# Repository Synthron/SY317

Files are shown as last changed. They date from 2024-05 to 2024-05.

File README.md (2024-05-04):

# Switching Power Supply Modules

## SY317
78xx compatible Switching Regulator

 - Input Voltage: 4.5V .. 24V
 - Output Voltage: 1.1V .. 16V
 - Output Current: 3A
 - Switching Frequency: 500kHz
 - Efficiency: 85-95% 
 - Output Ripple: <50mV

pincompatible to the popular 78xx series linear voltage regulators

Very small form factor at 10x25mm dimensions

## CB350
High current Switching Regulator

- 12..24V Input
- 5V2, 6V2, 7V4 and 8V4 fixed output
  - use solder bridge to select output voltage
  - different resistor values for voltages given in schematic
- 12A of current!

Intended for Servo Control, featuring 4 Pin-Headers for Servo control

features pin header for additional SY317 module for an additional variable 3A output voltage

compact form factor at 25x50mm dimensions

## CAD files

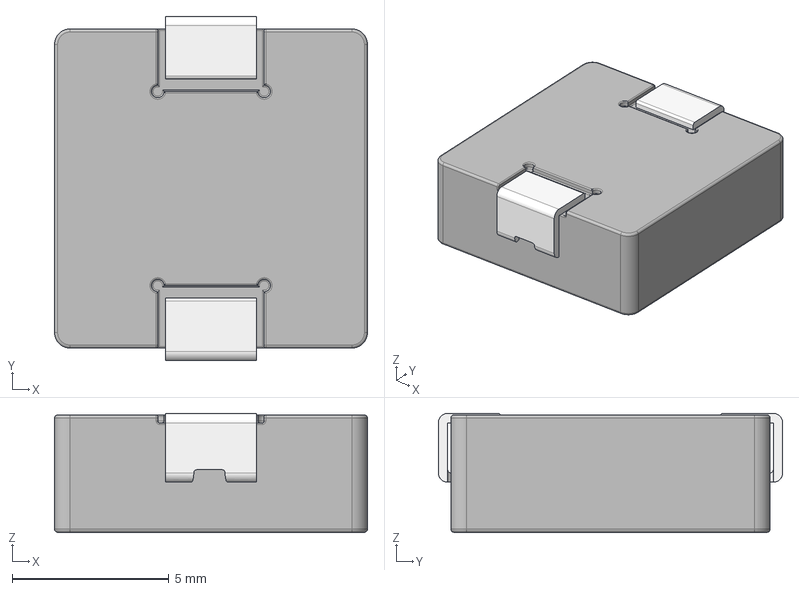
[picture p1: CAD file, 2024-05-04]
CB350/SRP1038C-150M.stp
10.0 x 11.0 x 3.81 mm

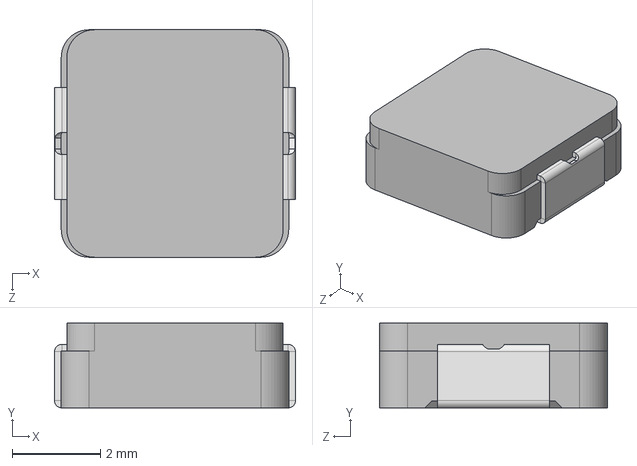
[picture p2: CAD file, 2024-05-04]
SY317/IHLP2020BZERR10M11.stp
5.45 x 1.92 x 5.15 mm

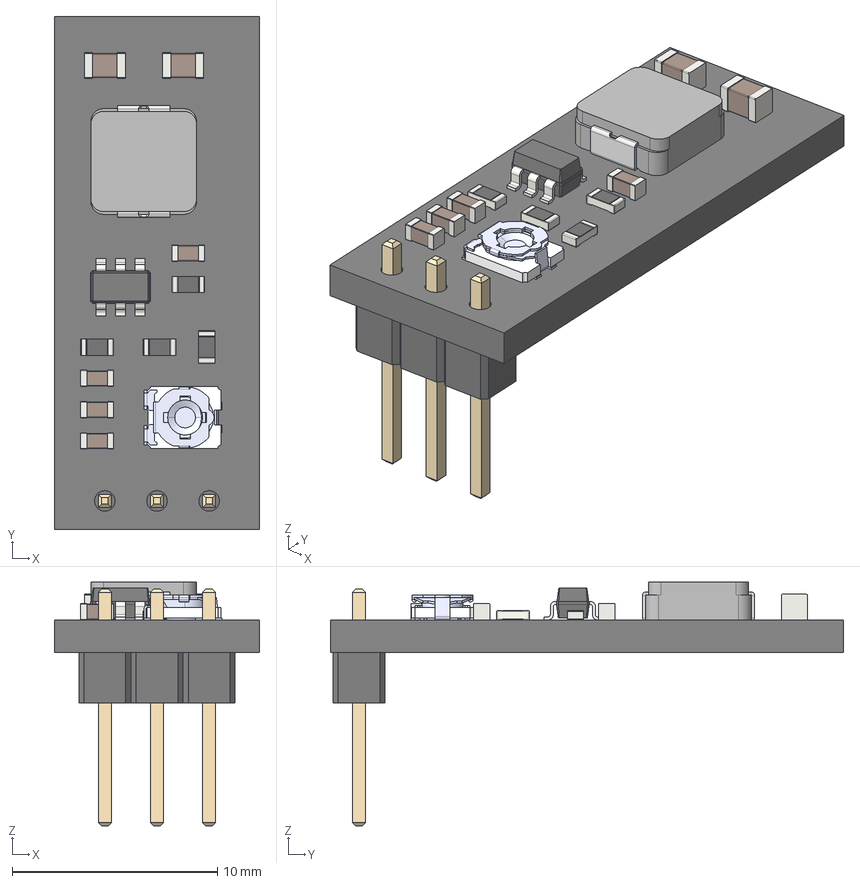
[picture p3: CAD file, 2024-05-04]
CB350/SY317_flat.step
10.0 x 25.0 x 11.9 mm
Local_CS_9149
Pcb_9149
PCB_Sketch_9149
C5_C_0805_2012Metric_e5cb0007d608 x 2
R2_R_0603_1608Metric_8ccc350c5da3 x 4
C2_C_0603_1608Metric_2aa61d0794fa x 4
L1_IHLP2020BZ_45d0cb963a33
TC33X-2-202E
TC33X-2-202E001
TC33X-2-202E002
TC33X-2-202E003
TC33X-2-202E004
TC33X-2-202E005
TC33X-2-202E006
TC33X-2-202E007
J1_PinHeader_1x03_P254mm_Vertical_3ddd89404d26
U1_SOT_23_6_10e227839481

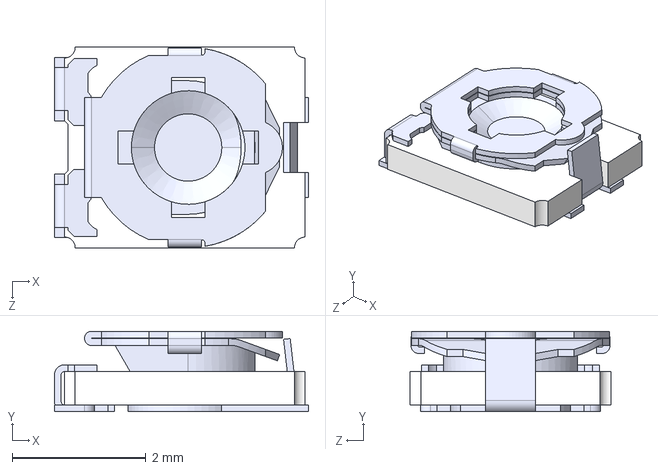
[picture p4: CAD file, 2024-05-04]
SY317/TC33X-2-101E.step
3.80 x 1.20 x 3.00 mm

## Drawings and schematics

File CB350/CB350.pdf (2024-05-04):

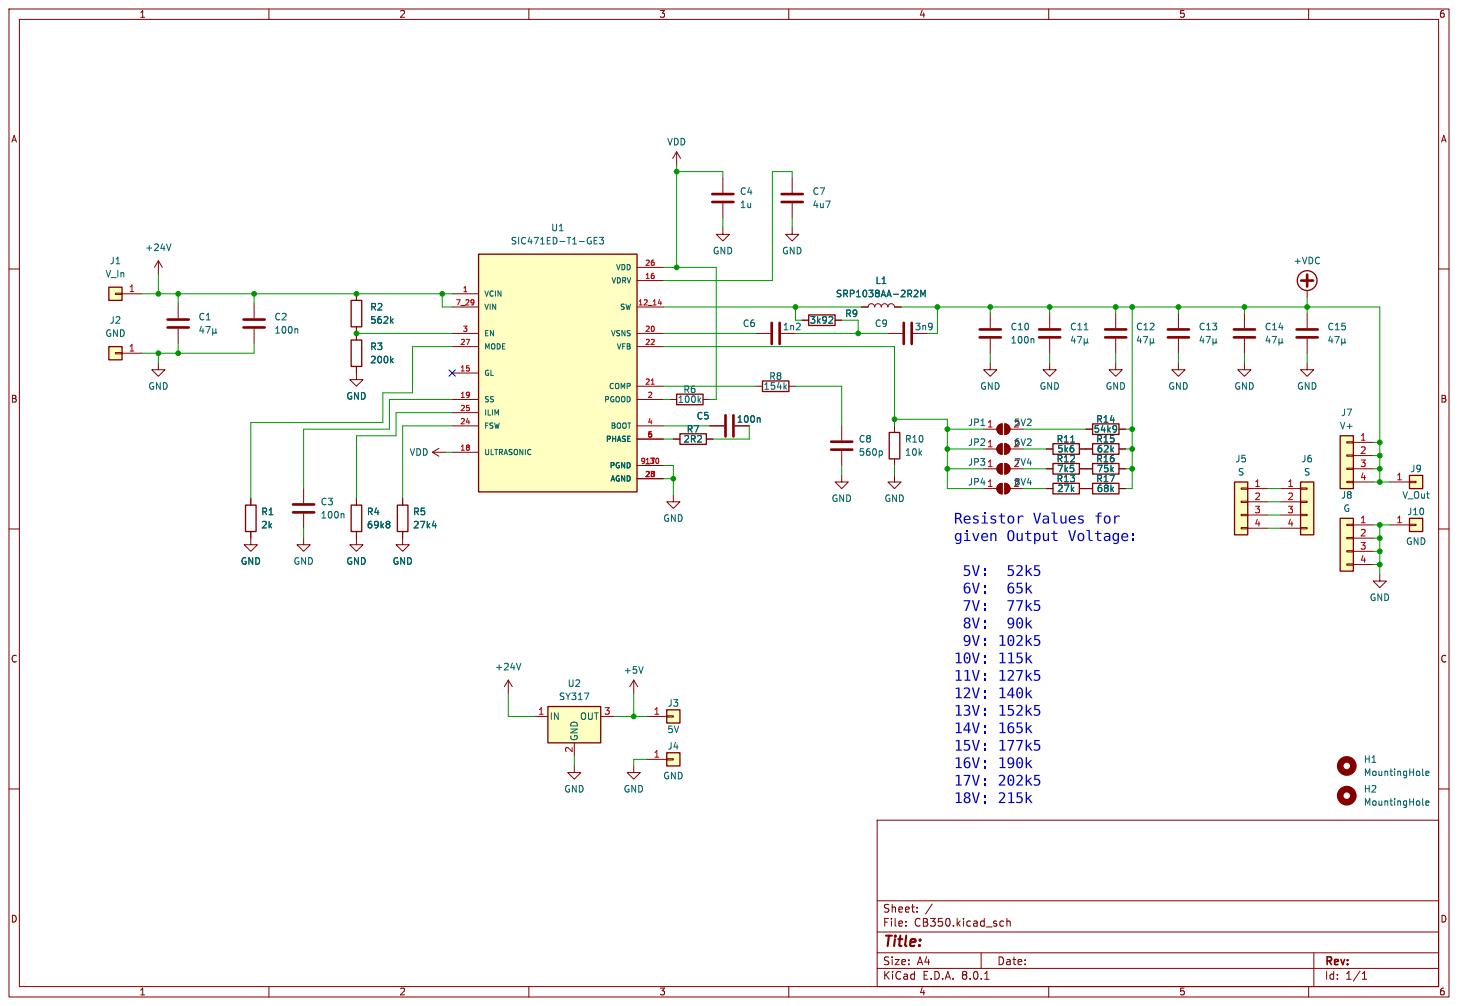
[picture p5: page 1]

Id: 1/1 Title: File: CB350.kicad_sch Sheet: / GND

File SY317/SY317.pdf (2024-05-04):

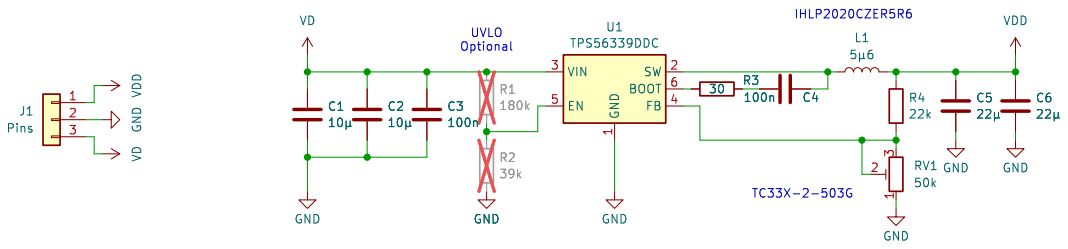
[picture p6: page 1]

1 SW 2 VIN 3 FB 4 EN 5 BOOT 6 U1 TPS56339DDC GND VD

Id: 1/1 Title: File: SY317.kicad_sch Sheet: / GND

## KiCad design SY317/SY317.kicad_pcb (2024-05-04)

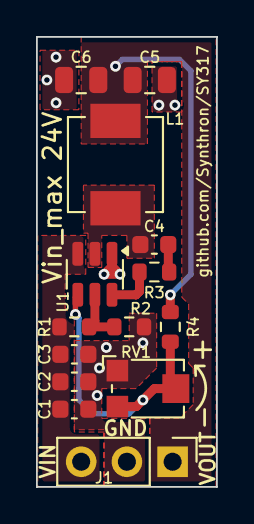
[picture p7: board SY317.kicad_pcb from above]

Board: 2 copper layers, 10.0 x 25.0 mm, 14 parts (0 on the bottom side), 8 nets.

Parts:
C1, C2: 10µ; C_0603_1608Metric
C3, C4: 100n; C_0603_1608Metric
C5, C6: 22µ; C_0805_2012Metric
J1: Conn_01x03; PinHeader_1x03_P2.54mm_Vertical
L1: 5µ6H; L_Vishay_IHLP-2020
R1: 180k; R_0603_1608Metric
R2: 39k; R_0603_1608Metric
R3: 30; R_0603_1608Metric
R4: 22k; R_0603_1608Metric
RV1: 50k; Potentiometer_Bourns_TC33X_Vertical
U1: TPS56339DDC; SOT-23-6

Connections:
GND: C1.2, C2.2, C3.2, C5.2, C6.2, J1.2, R2.2, RV1.1, U1.1 (GND)
unnamed: C4.1, R3.1
unnamed: R3.2, U1.6 (BOOT)
unnamed: R1.2, R2.1, U1.5 (EN)
unnamed: R4.2, RV1.2, RV1.3, U1.4 (FB)
unnamed: C4.2, L1.1, U1.2 (SW)
VD: C1.1, C2.1, C3.1, J1.3, R1.1, U1.3 (VIN)
VDD: C5.1, C6.1, J1.1, L1.2, R4.1

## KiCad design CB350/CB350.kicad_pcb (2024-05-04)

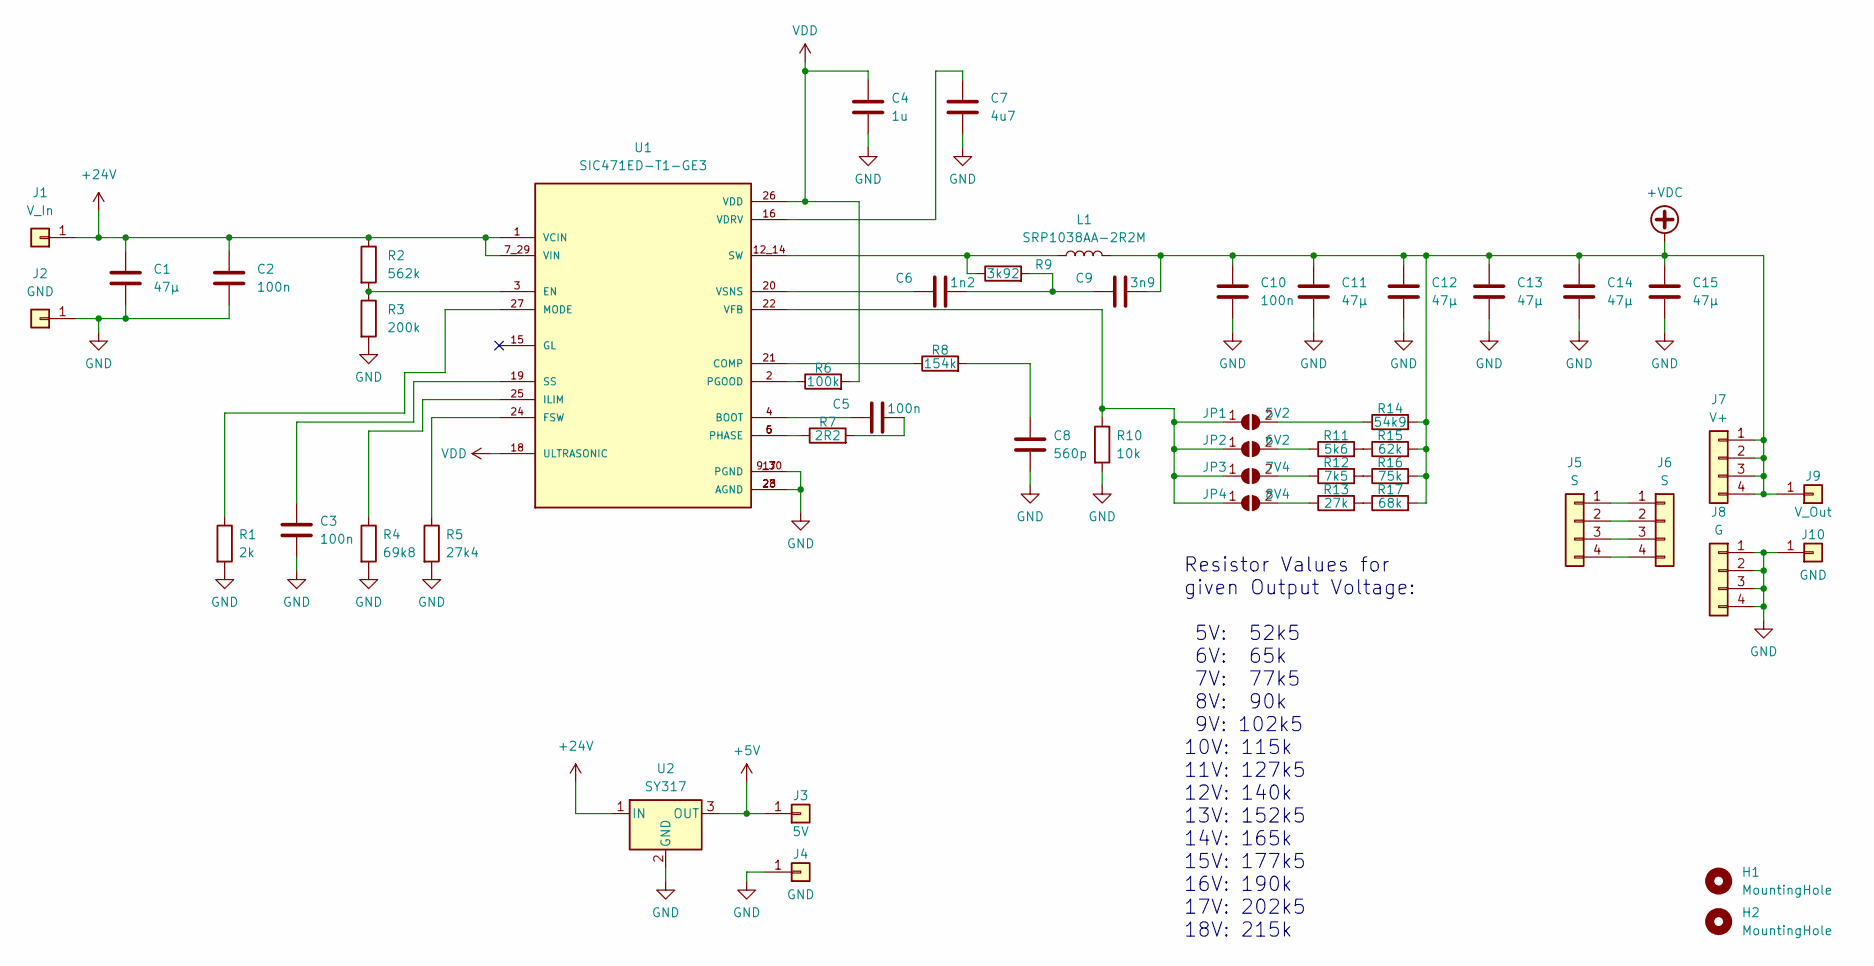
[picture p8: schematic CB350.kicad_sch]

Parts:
C1, C11, C12, C13, C14, C15: 47µ; C_1210_3225Metric
C2, C3, C5, C10: 100n; C_0603_1608Metric
C4: 1u; C_0603_1608Metric
C6: 1n2; C_0603_1608Metric
C7: 4u7; C_0603_1608Metric
C8: 560p; C_0603_1608Metric
C9: 3n9; C_0603_1608Metric
H1, H2: MountingHole; MountingHole_3.2mm_M3_DIN965
J1: V_In; TestPoint_THTPad_4.0x4.0mm_Drill2.0mm
J2, J10: GND; TestPoint_THTPad_4.0x4.0mm_Drill2.0mm
J3: 5V; TestPoint_THTPad_2.5x2.5mm_Drill1.2mm
J4: GND; TestPoint_THTPad_2.5x2.5mm_Drill1.2mm
J5, J6: S; PinHeader_1x04_P2.54mm_Vertical
J7: V+; PinHeader_1x04_P2.54mm_Vertical
J8: G; PinHeader_1x04_P2.54mm_Vertical
J9: V_Out; TestPoint_THTPad_4.0x4.0mm_Drill2.0mm
JP1: 5V2; SolderJumper-2_P1.3mm_Open_TrianglePad1.0x1.5mm
JP2: 6V2; SolderJumper-2_P1.3mm_Open_TrianglePad1.0x1.5mm
JP3: 7V4; SolderJumper-2_P1.3mm_Open_TrianglePad1.0x1.5mm
JP4: 8V4; SolderJumper-2_P1.3mm_Open_TrianglePad1.0x1.5mm
L1: SRP1038AA-2R2M; L_Bourns_SRP1038C_10.0x10.0mm
R1: 2k; R_0603_1608Metric
R2: 562k; R_0603_1608Metric
R3: 200k; R_0603_1608Metric
R4: 69k8; R_0603_1608Metric
R5: 27k4; R_0603_1608Metric
R6: 100k; R_0603_1608Metric
R7: 2R2; R_0603_1608Metric
R8: 154k; R_0603_1608Metric
R9: 3k92; R_0603_1608Metric
R10: 10k; R_0603_1608Metric
R11: 5k6; R_0603_1608Metric
R12: 7k5; R_0603_1608Metric
R13: 27k; R_0603_1608Metric
R14: 54k9; R_0603_1608Metric
R15: 62k; R_0603_1608Metric
R16: 75k; R_0603_1608Metric
R17: 68k; R_0603_1608Metric
U1: SIC471ED-T1-GE3; VREG_SIC471ED-T1-GE3; PARTREV D
U2: SY317; TO-220-3_Vertical

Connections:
+5V: J3.1, U2.3 (OUT)
+24V: C1.1, C2.1, J1.1, R2.1, U1.1 (VCIN), U1.7_29 (VIN), U2.1 (IN)
+VDC: C9.2, C10.1, C11.1, C12.1, C13.1, C14.1, C15.1, J7.1, J7.2, J7.3, J7.4, J9.1, L1.2, R14.2, R15.2, R16.2, R17.2
GND: C1.2, C2.2, C3.2, C4.2, C7.2, C8.2, C10.2, C11.2, C12.2, C13.2, C14.2, C15.2, J2.1, J4.1, J8.1, J8.2, J8.3, J8.4, J10.1, R1.2, R3.2, R4.2, R5.2, R10.2, U1.9_30 (PGND), U1.17 (PGND), U1.23 (AGND), U1.28 (AGND), U2.2 (GND)
unnamed: C5.2, R7.2
unnamed: C6.2, C9.1, R9.2
unnamed: C8.1, R8.2
unnamed: J5.1, J6.1
unnamed: J5.2, J6.2
unnamed: J5.3, J6.3
unnamed: J5.4, J6.4
unnamed: JP1.1 (A), JP2.1 (A), JP3.1 (A), JP4.1 (A), R10.1, U1.22 (VFB)
unnamed: JP1.2 (B), R14.1
unnamed: JP2.2 (B), R11.1
unnamed: JP3.2 (B), R12.1
unnamed: JP4.2 (B), R13.1
unnamed: R7.1, U1.5 (PHASE), U1.6 (PHASE)
unnamed: R11.2, R15.1
unnamed: R12.2, R16.1
unnamed: R13.2, R17.1
unnamed: C5.1, U1.4 (BOOT)
unnamed: R8.1, U1.21 (COMP)
unnamed: R2.2, R3.1, U1.3 (EN)
unnamed: R5.1, U1.24 (FSW)
unnamed: R4.1, U1.25 (ILIM)
unnamed: R1.1, U1.27 (MODE)
unnamed: R6.1, U1.2 (PGOOD)
unnamed: C3.1, U1.19 (SS)
unnamed: L1.1, R9.1, U1.12_14 (SW)
unnamed: C7.1, U1.16 (VDRV)
unnamed: C6.1, U1.20 (VSNS)
VDD: C4.1, R6.2, U1.18 (ULTRASONIC), U1.26 (VDD)

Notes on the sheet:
Resistor Values for given Output Voltage: 5V: 52k5 6V: 65k 7V: 77k5 8V: 90k 9V: 102k5 10V: 115k 11V: 127k5 12V: 140k 13V: 152k5 14V: 165k 15V: 177k5 16V: 190k 17V: 202k5 18V: 215k

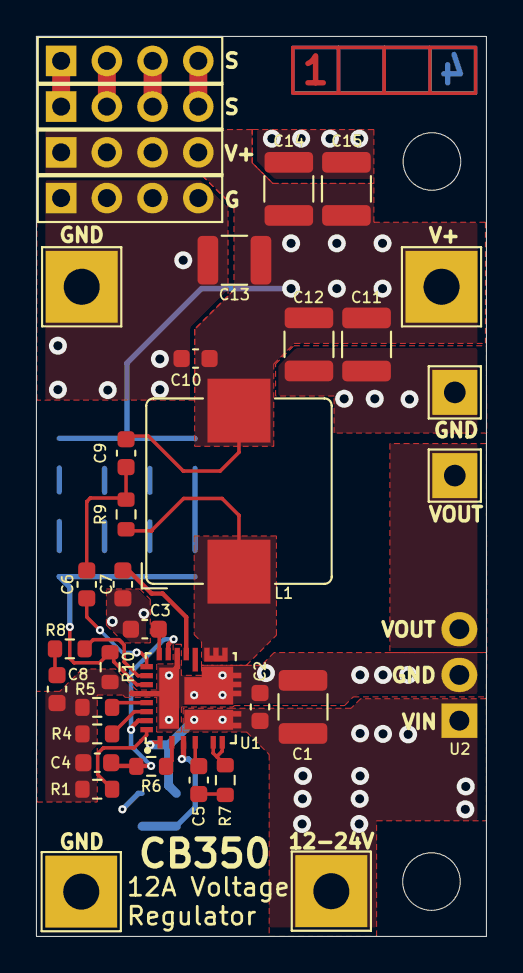
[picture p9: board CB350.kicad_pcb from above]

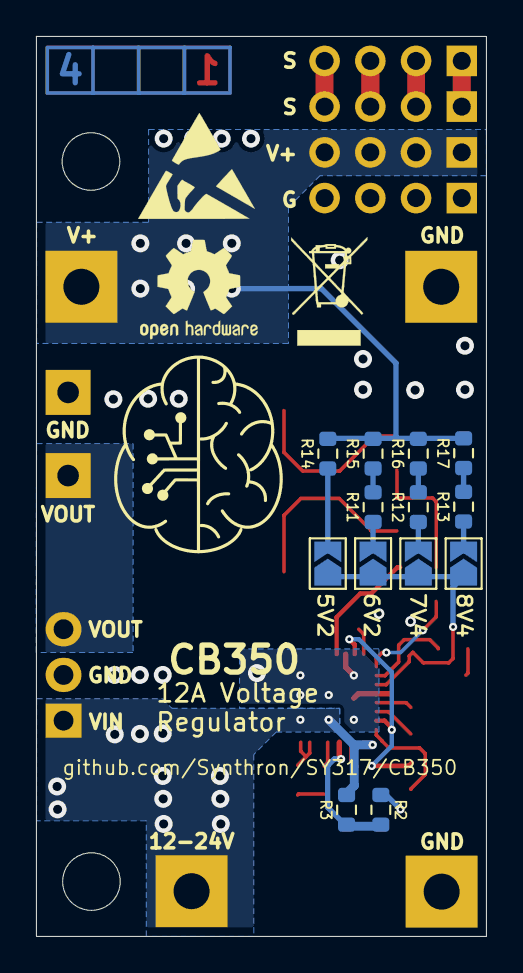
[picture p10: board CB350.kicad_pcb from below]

Board: 4 copper layers, 25.0 x 50.0 mm, 51 parts (13 on the bottom side), 32 nets.

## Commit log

2024-04-11 silkscreen fix
    [SY317.kicad_pcb]
2024-04-17 new module and readme update
    [CB350.kicad_pcb, CB350.kicad_sch, SY317.kicad_pcb]
2024-04-18 Update CB350 files, cleanup repo
    [CB350.kicad_pcb, CB350.kicad_sch, SY317.kicad_pcb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]
